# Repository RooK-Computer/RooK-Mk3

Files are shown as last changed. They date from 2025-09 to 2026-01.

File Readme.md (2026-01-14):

# RooK Mk3

RooK is a retro gaming console based on the Raspberry PI CM4. It has all the peripherials you need to be used as an old (modernish) console:

* HDMI for audio and video out.
* Barrel jack for 5V power input, because we love the simplicity of barrel jacks.
* an audio jack for, well... speakers!
* 4 USB ports for up to 4 modern gamepads.
* A cartridge slot!
* 3 Buttons to shut RooK down, exit the game and restart the game.

## How it all works

It's quite simple: instead of having an onboard SD card, the SD cards are installed onto separate PCBs for the cartridges. Once you put a cartridge in, RooK powers up and boots off the SD card in the cartridge.

Of course, unwrapping the SD cards can be tedious, so we built a cartridge reader.

It works out of the box with retropie, except for the three buttons. In this repository you find the software needed to enable those buttons. It's best done immediately after installing retropie, before you customize your setup.

## In this repository

There are 3 folders:

* software contains the sources for the .deb file to easily install overwatch and it's configuration. You'll find the .dep file in there as well, if you don't want to build it yourself. The source is compressed, as we have to ensure ownership and file privileges. Something git tends to ignore ;)
* PCBs contains all the designs for the PCBs involved: 
    * Cartridge - the PCB for cartridges
    * CartridgeReader - should be self-explanatory
    * KeyswitchCarrier - holds the switches for the three keys
    * Mainboard - the biggest of them.
    * Parts and CM4-Files are referenced in the aforementioned design files
* STLs contain the STL files for the case and the cartridge. You'll find our FreeCAD designs in there as well.

## I wanna build one!

Well for now, you have to produce and order the parts yourself. We're working on this. Stay tuned and keep an eye out at [rook.computer](https://rook.computer).

There is a building guide in the wiki.

## License

Unless noted otherwise this work is licensed under Creative Commons Attribution Share Alike 4.0 International.

`SPDX-License-Identifier:  CC-BY-SA-4.0`

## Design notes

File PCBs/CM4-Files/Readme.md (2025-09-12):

# CM4-Files

all files in this folder are files from the Raspberry PI Foundation and are referenced in our designs for footprints.

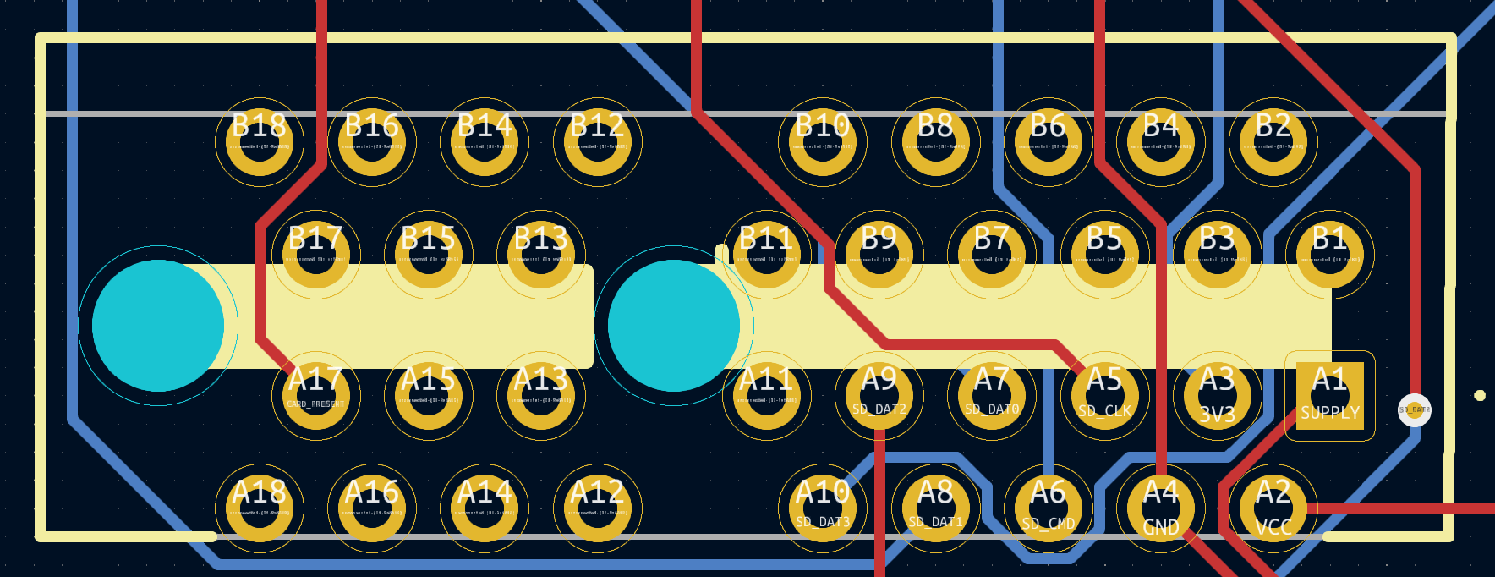
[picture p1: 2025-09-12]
PCBs/CartridgeReader/CartridgeMk3ReaderMk6/Connector.png

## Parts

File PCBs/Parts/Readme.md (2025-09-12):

# Parts

These are the parts used in various PCB designs. We will provide a list of the parts and what they are used for lateron.

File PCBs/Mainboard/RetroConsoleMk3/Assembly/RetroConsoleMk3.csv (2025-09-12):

Id | Designator | Footprint | Quantity | Designation | Supplier and ref
1 | R13,R12,R15,R11,R14,R16 | R_0201_0603Metric | 6 | 33
3 | C3 | C_0201_0603Metric | 1 | 10nF
4 | J7,J5,J6,J3 | USB_A_Molex_67643_Horizontal | 4 | USB_A
5 | J2 | SDCARD_MOLEX_503398-1892 | 1 | Micro_SD_Card
6 | J11 | JST_PH_B2B-PH-K_1x02_P2.00mm_Vertical | 1 | Reset
7 | C7,C5 | C_1206_3216Metric | 2 | 47uF
8 | J10 | SJ335083BTR | 1 | SJ3-35083B-TR
9 | J16,J15 | DF40C100DS04V51 | 2 | DF40C100DS04V51
10 | J8 | PJ114AHSMTTR | 1 | PJ-114AH-SMT-TR
11 | R7,R4 | R_0201_0603Metric | 2 | 220
12 | Y1 | 830108208209 | 1 | 830108208209
13 | R1 | R_0201_0603Metric | 1 | 1k
14 | J13 | JST_PH_B2B-PH-K_1x02_P2.00mm_Vertical | 1 | Quit
16 | R5,R8 | R_0201_0603Metric | 2 | 100
17 | IC2 | SOT65P210X110-6N | 1 | NC7WZ16P6X
18 | R6,R9 | R_0201_0603Metric | 2 | 1.8k
20 | D1 | LED_0201_0603Metric | 1 | GREEN
21 | C6,C4 | C_0201_0603Metric | 2 | 100nF
23 | R10 | R_0201_0603Metric | 1 | 10k
24 | J12 | JST_PH_B2B-PH-K_1x02_P2.00mm_Vertical | 1 | Shutdown
25 | C1,C2 | C_0201_0603Metric | 2 | 14pF
26 | TP5 | TestPoint_Pad_D3.0mm | 1 | GND_SUPPLY
27 | J1 | PinHeader_1x03_P2.54mm_Vertical | 1 | Conn_01x03_Socket
28 | J9 | 18710581 | 1 | 1871058-1
29 | J4 | HDMI_A_Molex_208658-1001_Horizontal | 1 | HDMI_A_1.4
30 | Q1 | IRF2804STRLPBF | 1 | IRLZ34NSTRLPBF
31 | J14 | JST_PH_B4B-PH-K_1x04_P2.00mm_Vertical | 1 | Keys
33 | R2 | R_0201_0603Metric | 1 | 100k
34 | R3 | R_0201_0603Metric | 1 | 12k (+/- 1%)
35 | IC1 | QFN50P600X600X100-37N-D | 1 | USB2514B_M2

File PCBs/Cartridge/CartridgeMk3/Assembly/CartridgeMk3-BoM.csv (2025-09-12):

Id | Designator | Footprint | Quantity | Designation | Supplier and ref
2 | R1,R3,R5,R2,R4 | R_0201_0603Metric | 5 | 10k
3 | J2 | SDCARD_MOLEX_503398-1892 | 1 | Micro_SD_Card

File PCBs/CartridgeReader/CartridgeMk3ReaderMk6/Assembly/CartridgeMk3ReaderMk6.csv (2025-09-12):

Id | Designator | Footprint | Quantity | Designation | Supplier and ref
1 | R3 | R_0201_0603Metric | 1 | 12k +/-1%
2 | R4,R5 | R_0201_0603Metric | 2 | 1k
4 | C4,C3 | C_0201_0603Metric | 2 | 1.0 uF +/- 20%
5 | C6 | C_1206_3216Metric | 1 | 22 uF
6 | R8,R11,R6,R9,R10,R7 | R_0201_0603Metric | 6 | 33
7 | IC1 | QFN50P600X600X90-37N-D | 1 | USB2244I-AEZG-06-TR | https://cn.mouser.com/ProductDetail/Microchip-Technology/USB2244I-AEZG-06-TR
8 | L1 | 74404054470 | 1 | 47 muH | https://cn.mouser.com/ProductDetail/Wurth-Elektronik/74404054470?qs=Zt3UNFD9mQjCehaSX3JlDg%3D%3D
9 | R1,R2 | R_0201_0603Metric | 2 | 5k1
10 | C5 | C_0201_0603Metric | 1 | 1 uF
11 | J1 | 18710581 | 1 | 1871058-1 | https://cn.mouser.com/ProductDetail/TE-Connectivity/1871058-1?qs=%252BoxYCnKeKt%252BrW4wNNMzC1A%3D%3D
12 | Y1 | 830108208209 | 1 | 830108208209 | https://cn.mouser.com/ProductDetail/Wurth-Elektronik/830108208209?qs=hWgE7mdIu5Qfk68EXTEoAw%3D%3D
13 | C2,C1 | C_0201_0603Metric | 2 | 14pF
15 | J2 | USB_C_Receptacle_Molex_105450-0101 | 1 | USB_C_Receptacle
16 | C8 | C_1206_3216Metric | 1 | 4.7 uF
18 | IC2 | ADPL16000AATAT | 1 | ADPL16000AATA+T | https://cn.mouser.com/ProductDetail/Analog-Devices-Maxim-Integrated/ADPL16000AATA%2bT
20 | C7 | C_1206_3216Metric | 1 | 1uF

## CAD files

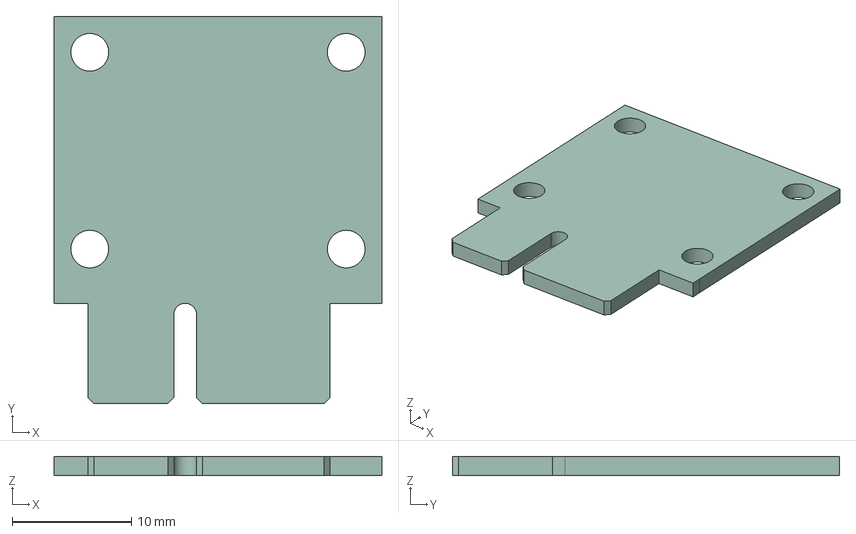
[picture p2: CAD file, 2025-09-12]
PCBs/Cartridge/CartridgeMk3/CartridgeMk1_simple.step
27.5 x 32.5 x 1.60 mm

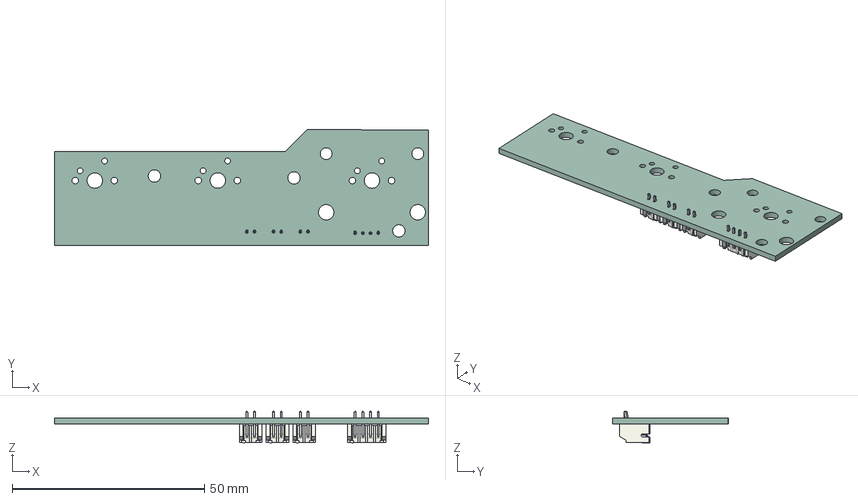
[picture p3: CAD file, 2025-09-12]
PCBs/KeyswitchCarrier/KeyswitchCarrierMk3/KeyswitchCarrierMk3.step
97.2 x 30.0 x 8.25 mm
JST_S4B_PH_K
JST_S2B_PH_K x 3
KeyswitchCarrierMk3_PCB

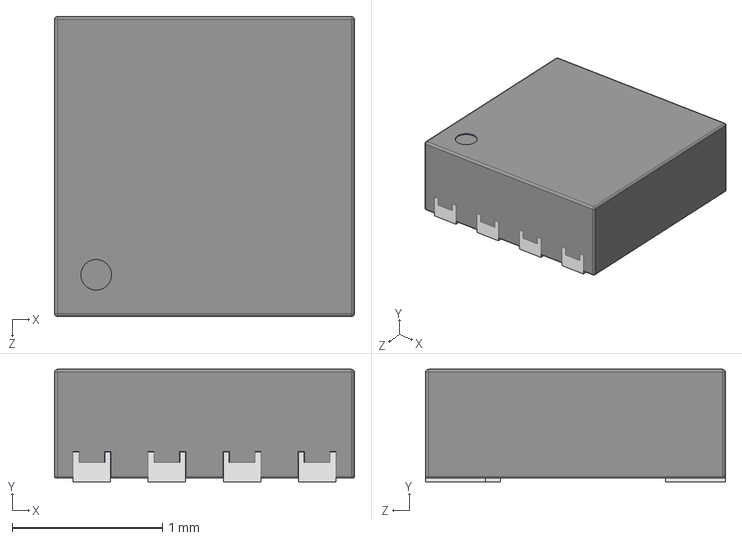
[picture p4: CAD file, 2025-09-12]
PCBs/Parts/LIB_ADPL16000AATA+T/ADPL16000AATA+T/3D/ADPL16000AATA+T.stp
2.00 x 0.75 x 2.00 mm

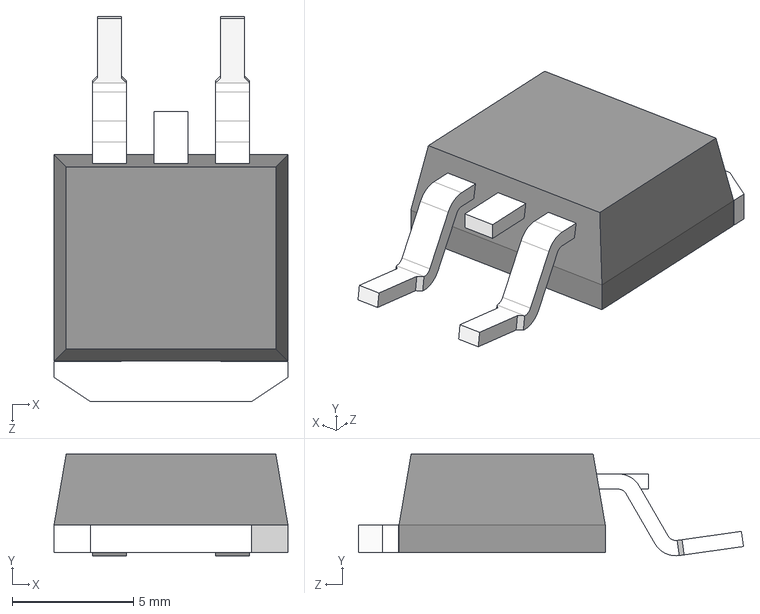
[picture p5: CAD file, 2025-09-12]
PCBs/Parts/LIB_IRLZ34NSTRLPBF/IRLZ34NSTRLPBF/3D/IRLZ34NSTRLPBF.stp
9.65 x 4.19 x 15.9 mm

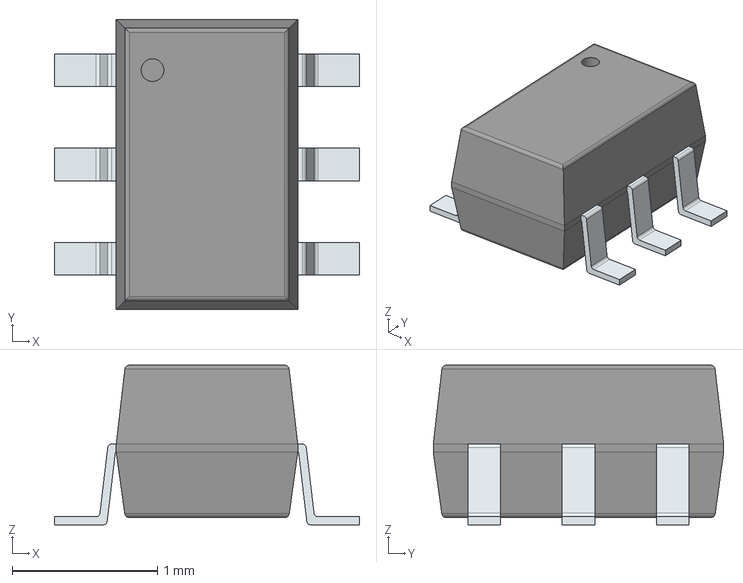
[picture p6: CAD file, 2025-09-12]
PCBs/Parts/LIB_NC7WZ16P6X/NC7WZ16P6X/3D/NC7WZ16P6X.stp
2.10 x 2.00 x 1.10 mm
PinsArrayLR

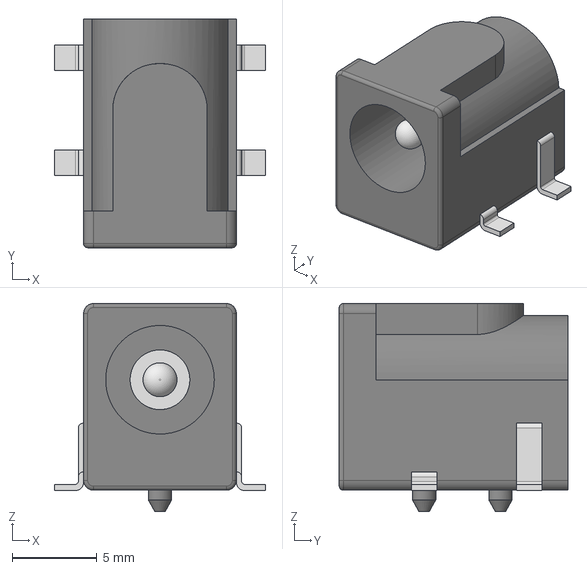
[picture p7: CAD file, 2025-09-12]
PCBs/Parts/LIB_PJ-114AH-SMT-TR/PJ-114AH-SMT-TR/3D/PJ-114AH-SMT-TR.stp
12.4 x 13.5 x 12.3 mm

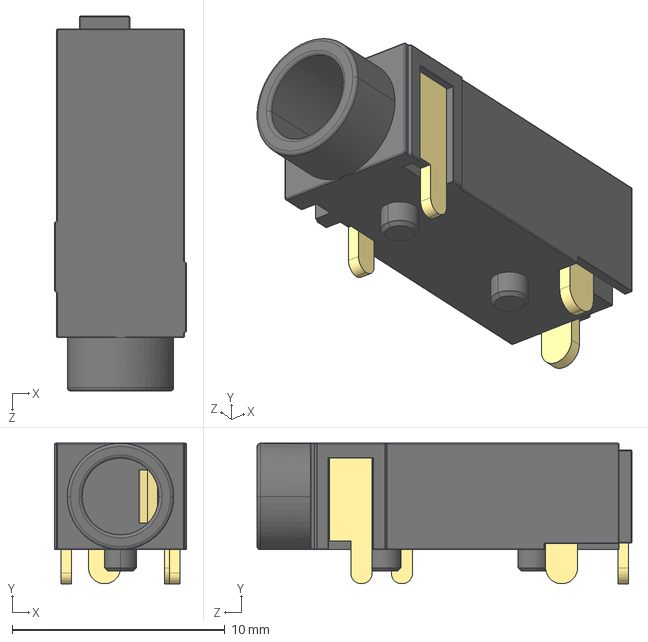
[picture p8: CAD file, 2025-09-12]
PCBs/Parts/LIB_SJ3-35083B-TR/SJ3-35083B-TR/3D/SJ3-35083B-TR.stp
6.20 x 6.60 x 17.6 mm

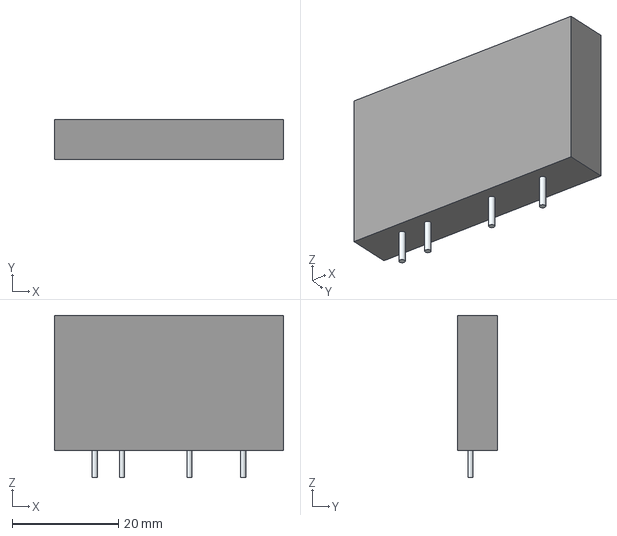
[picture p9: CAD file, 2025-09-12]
PCBs/Parts/LIB_SSRC-240D5/SSRC-240D5/3D/SSRC-240D5.stp
43.1 x 7.60 x 30.5 mm
Leads

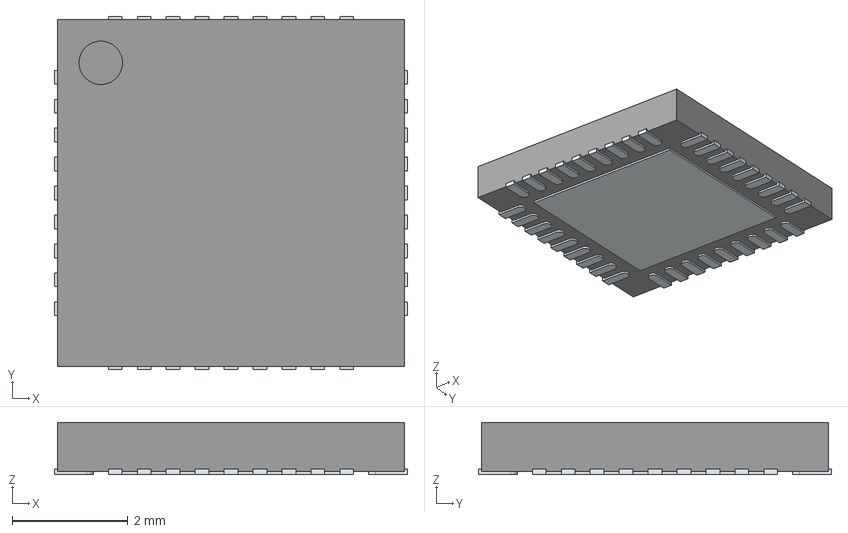
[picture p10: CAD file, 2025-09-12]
PCBs/Parts/LIB_USB2244I-AEZG-06-TR/USB2244I-AEZG-06-TR/3D/USB2244I-AEZG-06-TR.stp
6.10 x 6.10 x 0.9 mm
ThermalPin
PinsArrayLR
PinsArrayTB

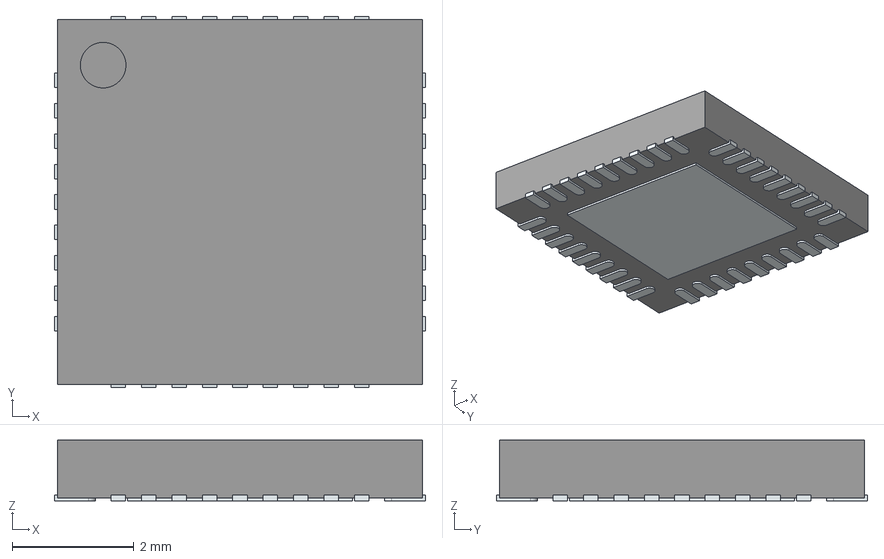
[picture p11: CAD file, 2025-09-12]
PCBs/Parts/LIB_USB2514B_M2/USB2514B_M2/3D/USB2514B_M2.stp
6.10 x 6.10 x 1.00 mm
ThermalPin
PinsArrayLR
PinsArrayTB

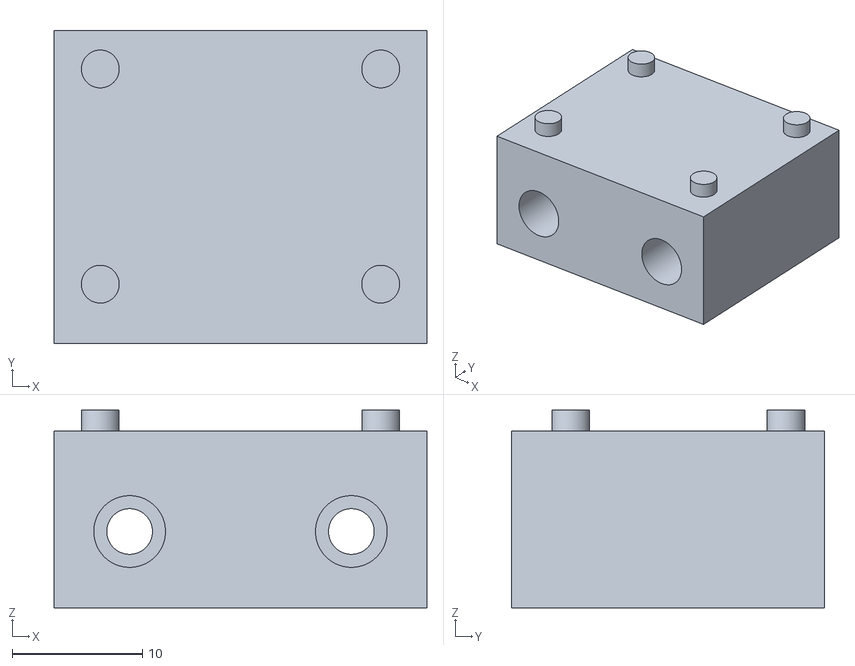
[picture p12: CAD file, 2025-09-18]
STLs/LegoInspiredCase_by_Konnexus_Mk1/CartridgeMk2-STLs/CartridgeMk2-BackSide.stl
28.6 x 24.0 x 15.2

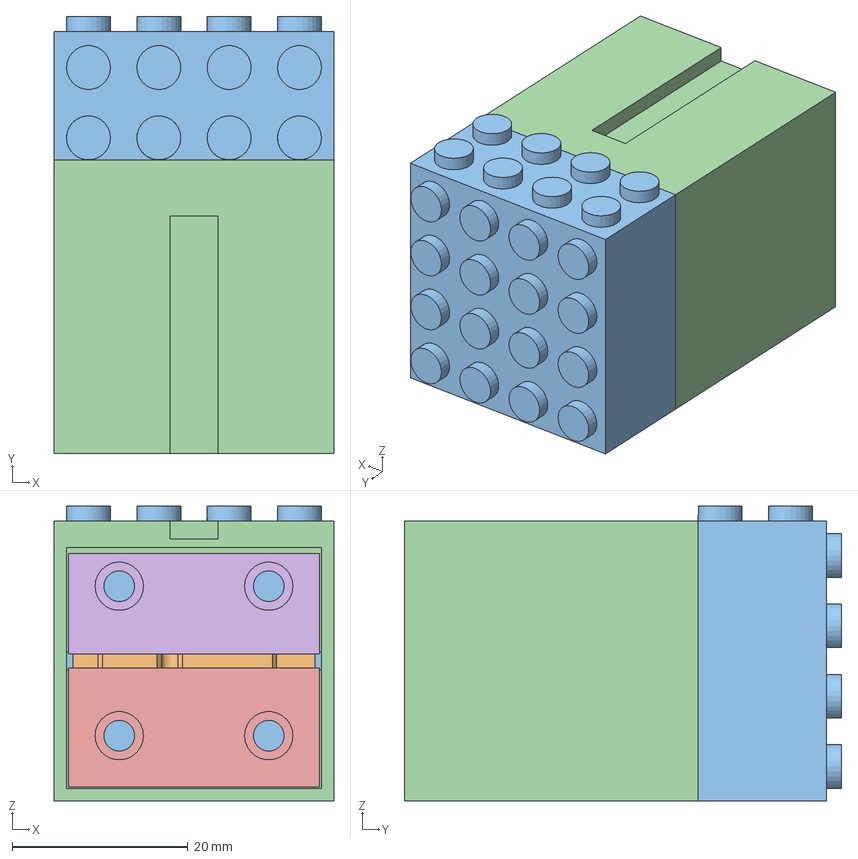
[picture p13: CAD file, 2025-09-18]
STLs/LegoInspiredCase_by_Konnexus_Mk1/CartridgeMk2.FCStd
31.8 x 49.7 x 33.5 mm
CartridgeMk1_PCB
TopPanel
Housing
BackSide
FrontSide

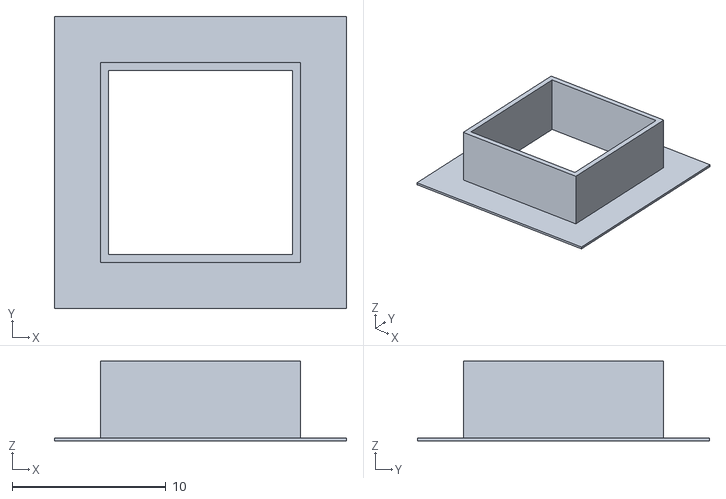
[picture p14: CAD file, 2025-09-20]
STLs/LegoInspiredCase_by_Konnexus_Mk1/Case-STLs/LegoCase_Konnexus_Mk1-Shutdown Button Border.stl
19.0 x 19.0 x 5.20

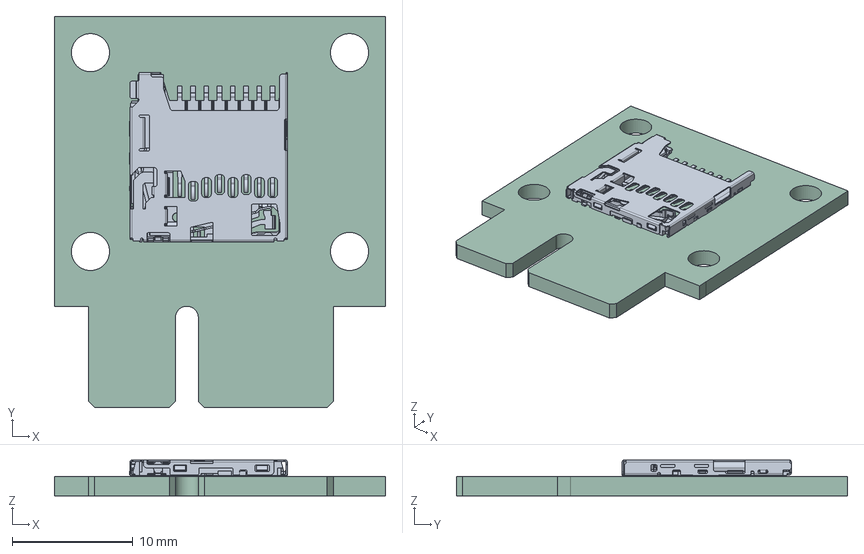
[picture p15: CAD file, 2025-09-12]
PCBs/Cartridge/CartridgeMk3/CartridgeMk3.step
27.5 x 32.5 x 2.98 mm
CartridgeMk1_PCB

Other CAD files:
STLs/LegoInspiredCase_by_Konnexus_Mk1/CartridgeMk2-STLs/CartridgeMk2-TopPanel.stl
STLs/LegoInspiredCase_by_Konnexus_Mk1/Case-STLs/LegoCase_Konnexus_Mk1-Reset Button fat Border.stl
STLs/LegoInspiredCase_by_Konnexus_Mk1/CartridgeMk2-STLs/CartridgeMk2-FrontSide.stl
STLs/LegoInspiredCase_by_Konnexus_Mk1/Case-STLs/LegoCase_Konnexus_Mk1-Quit Button fat Border.stl
PCBs/Parts/105450-0101/3D/105450-0101.stp
PCBs/Parts/LIB_1871058-1/1871058-1/3D/1871058-1.stp
PCBs/Parts/LIB_1871058-1/1871058-1/Allegro/18710581.psm
PCBs/Parts/LIB_1871058-1/1871058-1/DEHDL/1871058_1/chips/chips.prt
PCBs/Parts/LIB_74404054470/74404054470/3D/74404054470.stp
PCBs/Parts/LIB_74404054470/74404054470/Allegro/74404054470.psm
PCBs/Parts/LIB_74404054470/74404054470/DEHDL/74404054470/chips/chips.prt
PCBs/Parts/LIB_830108208209/830108208209/3D/830108208209.stp
PCBs/Parts/LIB_830108208209/830108208209/Allegro/830108208209.psm
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

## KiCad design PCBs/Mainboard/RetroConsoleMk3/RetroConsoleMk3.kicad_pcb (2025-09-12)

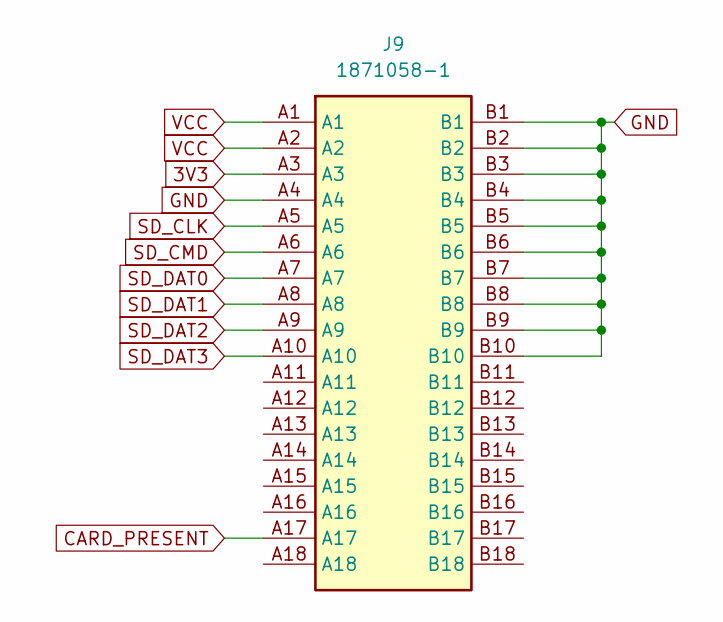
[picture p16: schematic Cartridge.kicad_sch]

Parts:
J9: 1871058-1; 18710581; Manufacturer_Part_Number 1871058-1; Mouser Part Number 571-1871058-1

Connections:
3V3: J9.A3; also elsewhere on the board
CARD_PRESENT: J9.A17; also elsewhere on the board
GND: J9.A4, J9.B1, J9.B2, J9.B3, J9.B4, J9.B5, J9.B6, J9.B7, J9.B8, J9.B9, J9.B10; also elsewhere on the board
SD_CLK: J9.A5; also elsewhere on the board
SD_CMD: J9.A6; also elsewhere on the board
SD_DAT0: J9.A7; also elsewhere on the board
SD_DAT1: J9.A8; also elsewhere on the board
SD_DAT2: J9.A9; also elsewhere on the board
SD_DAT3: J9.A10; also elsewhere on the board
VCC: J9.A1, J9.A2; also elsewhere on the board

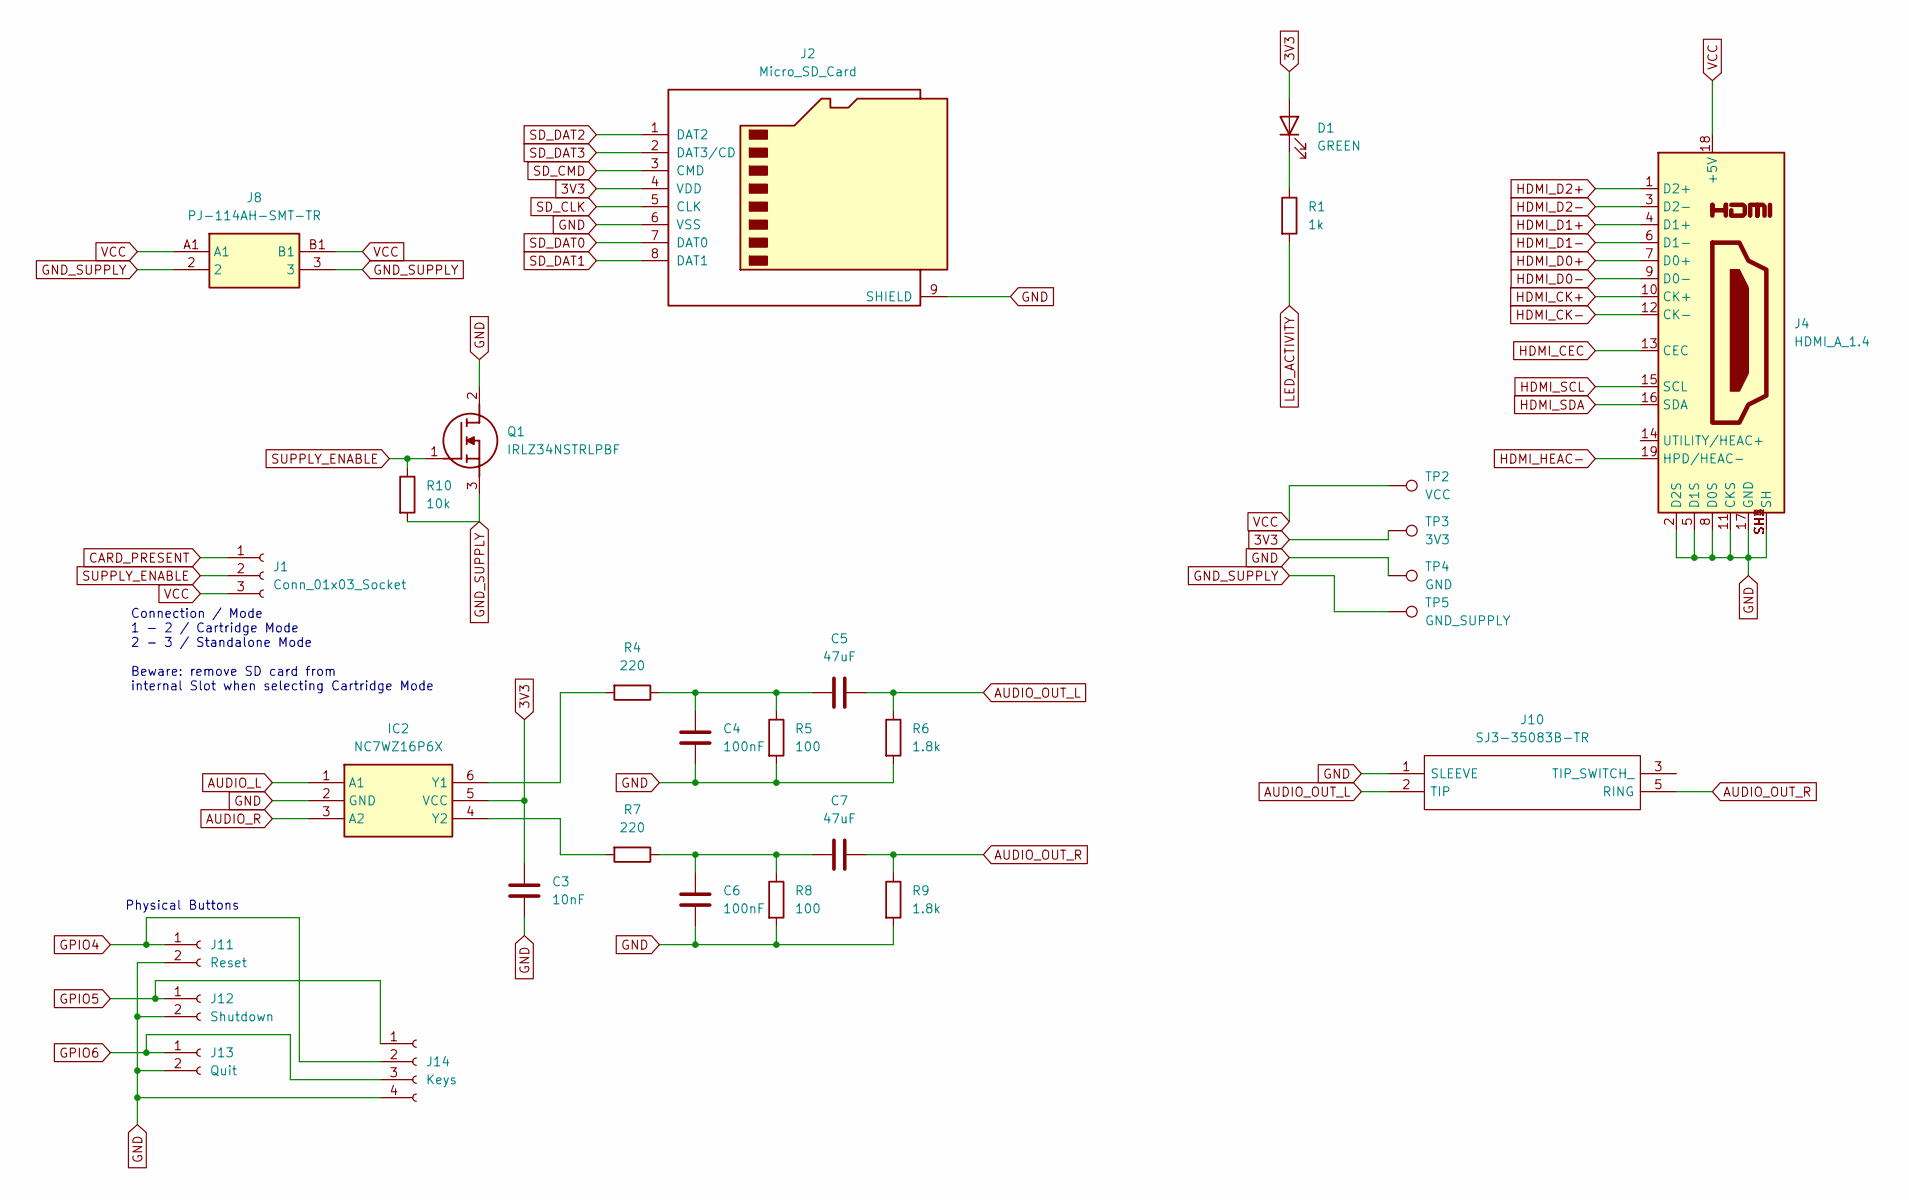
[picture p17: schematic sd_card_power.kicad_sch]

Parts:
C3: 10nF; C_0201_0603Metric
C4, C6: 100nF; C_0201_0603Metric
C5, C7: 47uF; C_1206_3216Metric
D1: GREEN; LED_0201_0603Metric
IC2: NC7WZ16P6X; SOT65P210X110-6N; Manufacturer_Part_Number NC7WZ16P6X; Mouser Part Number 512-NC7WZ16P6X
J1: Conn_01x03_Socket; PinHeader_1x03_P2.54mm_Vertical
J2: Micro_SD_Card; SDCARD_MOLEX_503398-1892
J4: HDMI_A_1.4; HDMI_A_Molex_208658-1001_Horizontal
J8: PJ-114AH-SMT-TR; PJ114AHSMTTR; Manufacturer_Part_Number PJ-114AH-SMT-TR; Mouser Part Number 179-PJ-114AH-SMT-TR
J10: SJ3-35083B-TR; SJ335083BTR; Manufacturer_Part_Number SJ3-35083B-TR; Mouser Part Number 179-SJ3-35083B-TR
J11: Reset; JST_PH_B2B-PH-K_1x02_P2.00mm_Vertical
J12: Shutdown; JST_PH_B2B-PH-K_1x02_P2.00mm_Vertical
J13: Quit; JST_PH_B2B-PH-K_1x02_P2.00mm_Vertical
J14: Keys; JST_PH_B4B-PH-K_1x04_P2.00mm_Vertical
Q1: IRLZ34NSTRLPBF; IRF2804STRLPBF; Manufacturer_Part_Number IRLZ34NSTRLPBF; Mouser Part Number 942-IRLZ34NSTRLPBF
R1: 1k; R_0201_0603Metric
R4, R7: 220; R_0201_0603Metric
R5, R8: 100; R_0201_0603Metric
R6, R9: 1.8k; R_0201_0603Metric
R10: 10k; R_0201_0603Metric
TP2: VCC; TestPoint_Pad_D3.0mm
TP3: 3V3; TestPoint_Pad_D3.0mm
TP4: GND; TestPoint_Pad_D3.0mm
TP5: GND_SUPPLY; TestPoint_Pad_D3.0mm

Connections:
3V3: C3.1, D1.2 (A), IC2.5 (VCC), J2.4 (VDD), TP3.1; also elsewhere on the board
AUDIO_L: IC2.1 (A1); also elsewhere on the board
AUDIO_OUT_L: C5.1, J10.2 (TIP), R6.1
AUDIO_OUT_R: C7.1, J10.5 (RING), R9.1
AUDIO_R: IC2.3 (A2); also elsewhere on the board
CARD_PRESENT: J1.1; also elsewhere on the board
GND: C3.2, C4.2, C6.2, IC2.2 (GND), J2.6 (VSS), J2.9 (SHIELD), J4.2 (D2S), J4.5 (D1S), J4.8 (D0S), J4.11 (CKS), J4.17 (GND), J4.SH1 (SH), J4.SH2 (SH), J4.SH3 (SH), J4.SH4 (SH), J10.1 (SLEEVE), J11.2, J12.2, J13.2, J14.4, Q1.2 (D), R5.2, R6.2, R8.2, R9.2, TP4.1; also elsewhere on the board
GND_SUPPLY: J8.2, J8.3, Q1.3 (S), R10.2, TP5.1
GPIO4: J11.1, J14.2; also elsewhere on the board
GPIO5: J12.1, J14.1; also elsewhere on the board
GPIO6: J13.1, J14.3; also elsewhere on the board
HDMI_CEC: J4.13 (CEC); also elsewhere on the board
HDMI_CK+: J4.10 (CK+); also elsewhere on the board
HDMI_CK-: J4.12 (CK-); also elsewhere on the board
HDMI_D0+: J4.7 (D0+); also elsewhere on the board
HDMI_D0-: J4.9 (D0-); also elsewhere on the board
HDMI_D1+: J4.4 (D1+); also elsewhere on the board
HDMI_D1-: J4.6 (D1-); also elsewhere on the board
HDMI_D2+: J4.1 (D2+); also elsewhere on the board
HDMI_D2-: J4.3 (D2-); also elsewhere on the board
HDMI_HEAC-: J4.19 (HPD/HEAC-); also elsewhere on the board
HDMI_SCL: J4.15 (SCL); also elsewhere on the board
HDMI_SDA: J4.16 (SDA); also elsewhere on the board
LED_ACTIVITY: R1.2; also elsewhere on the board
unnamed: C4.1, C5.2, R4.1, R5.1
unnamed: C6.1, C7.2, R7.1, R8.1
unnamed: D1.1 (K), R1.1
unnamed: IC2.6 (Y1), R4.2
unnamed: IC2.4 (Y2), R7.2
SD_CLK: J2.5 (CLK); also elsewhere on the board
SD_CMD: J2.3 (CMD); also elsewhere on the board
SD_DAT0: J2.7 (DAT0); also elsewhere on the board
SD_DAT1: J2.8 (DAT1); also elsewhere on the board
SD_DAT2: J2.1 (DAT2); also elsewhere on the board
SD_DAT3: J2.2 (DAT3/CD); also elsewhere on the board
SUPPLY_ENABLE: J1.2, Q1.1 (G), R10.1
VCC: J1.3, J4.18 (+5V), J8.A1, J8.B1, TP2.1; also elsewhere on the board

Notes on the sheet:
Physical Buttons
Connection / Mode 1 - 2 / Cartridge Mode 2 - 3 / Standalone Mode Beware: remove SD card from internal Slot when selecting Cartridge Mode

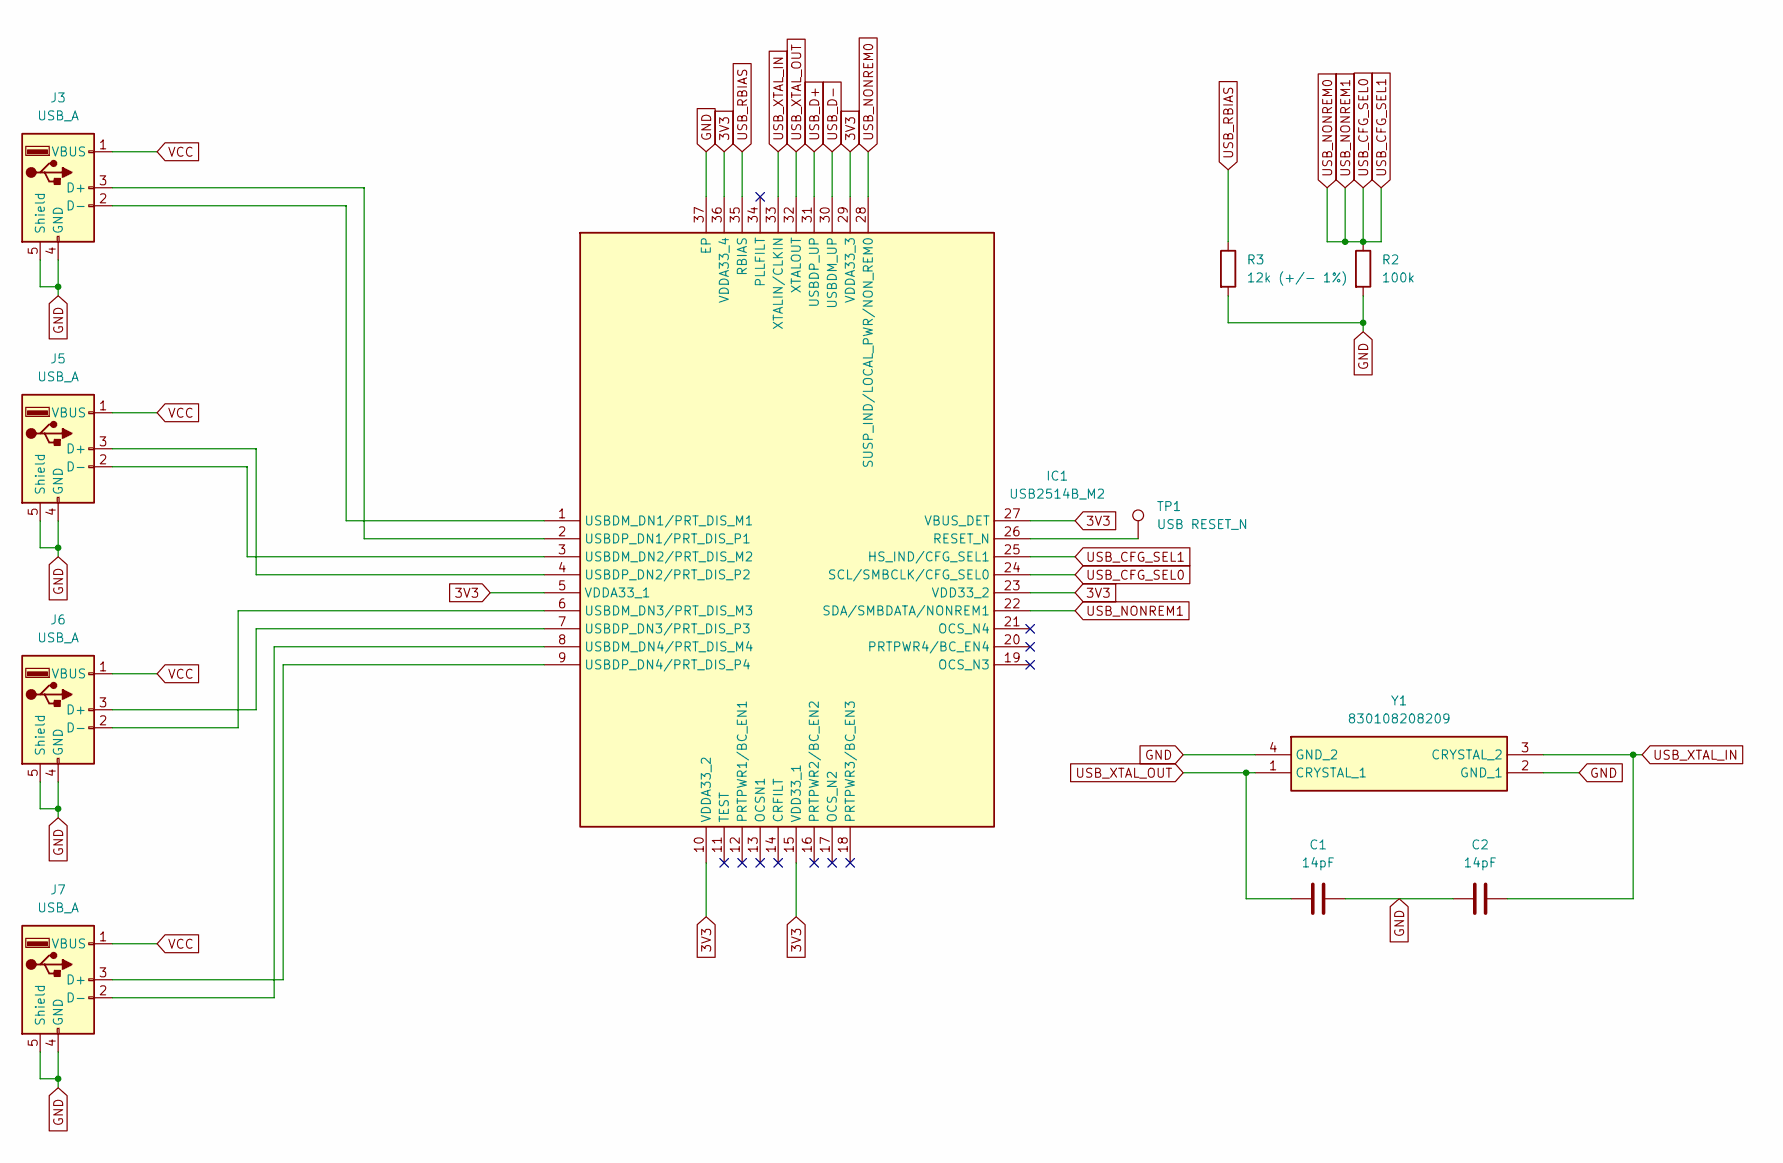
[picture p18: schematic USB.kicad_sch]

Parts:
C1, C2: 14pF; C_0201_0603Metric
IC1: USB2514B_M2; QFN50P600X600X100-37N-D; Manufacturer_Part_Number USB2514B/M2; Mouser Part Number 579-USB2514B/M2
J3, J5, J6, J7: USB_A; USB_A_Molex_67643_Horizontal
R2: 100k; R_0201_0603Metric
R3: 12k (+/- 1%); R_0201_0603Metric
TP1: USB RESET_N; TestPoint_Pad_D3.0mm
Y1: 830108208209; Manufacturer_Part_Number 830108208209; Mouser Part Number 710-830108208209

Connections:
3V3: IC1.5 (VDDA33_1), IC1.10 (VDDA33_2), IC1.15 (VDD33_1), IC1.23 (VDD33_2), IC1.27 (VBUS_DET), IC1.29 (VDDA33_3), IC1.36 (VDDA33_4); also elsewhere on the board
GND: C1.1, C2.2, IC1.37 (EP), J3.4 (GND), J3.5 (Shield), J5.4 (GND), J5.5 (Shield), J6.4 (GND), J6.5 (Shield), J7.4 (GND), J7.5 (Shield), R2.2, R3.2, Y1.2 (GND_1), Y1.4 (GND_2); also elsewhere on the board
unnamed: IC1.26 (RESET_N), TP1.1
unnamed: IC1.1 (USBDM_DN1/PRT_DIS_M1), J3.2 (D-)
unnamed: IC1.3 (USBDM_DN2/PRT_DIS_M2), J5.2 (D-)
unnamed: IC1.6 (USBDM_DN3/PRT_DIS_M3), J6.2 (D-)
unnamed: IC1.8 (USBDM_DN4/PRT_DIS_M4), J7.2 (D-)
unnamed: IC1.2 (USBDP_DN1/PRT_DIS_P1), J3.3 (D+)
unnamed: IC1.4 (USBDP_DN2/PRT_DIS_P2), J5.3 (D+)
unnamed: IC1.7 (USBDP_DN3/PRT_DIS_P3), J6.3 (D+)
unnamed: IC1.9 (USBDP_DN4/PRT_DIS_P4), J7.3 (D+)
USB_CFG_SEL0: IC1.22 (SDA/SMBDATA/NONREM1), IC1.24 (SCL/SMBCLK/CFG_SEL0), IC1.25 (HS_IND/CFG_SEL1), IC1.28 (SUSP_IND/LOCAL_PWR/NON_REM0), R2.1
USB_D+: IC1.31 (USBDP_UP); also elsewhere on the board
USB_D-: IC1.30 (USBDM_UP); also elsewhere on the board
USB_RBIAS: IC1.35 (RBIAS), R3.1
USB_XTAL_IN: C2.1, IC1.33 (XTALIN/CLKIN), Y1.3 (CRYSTAL_2)
USB_XTAL_OUT: C1.2, IC1.32 (XTALOUT), Y1.1 (CRYSTAL_1)
VCC: J3.1 (VBUS), J5.1 (VBUS), J6.1 (VBUS), J7.1 (VBUS); also elsewhere on the board

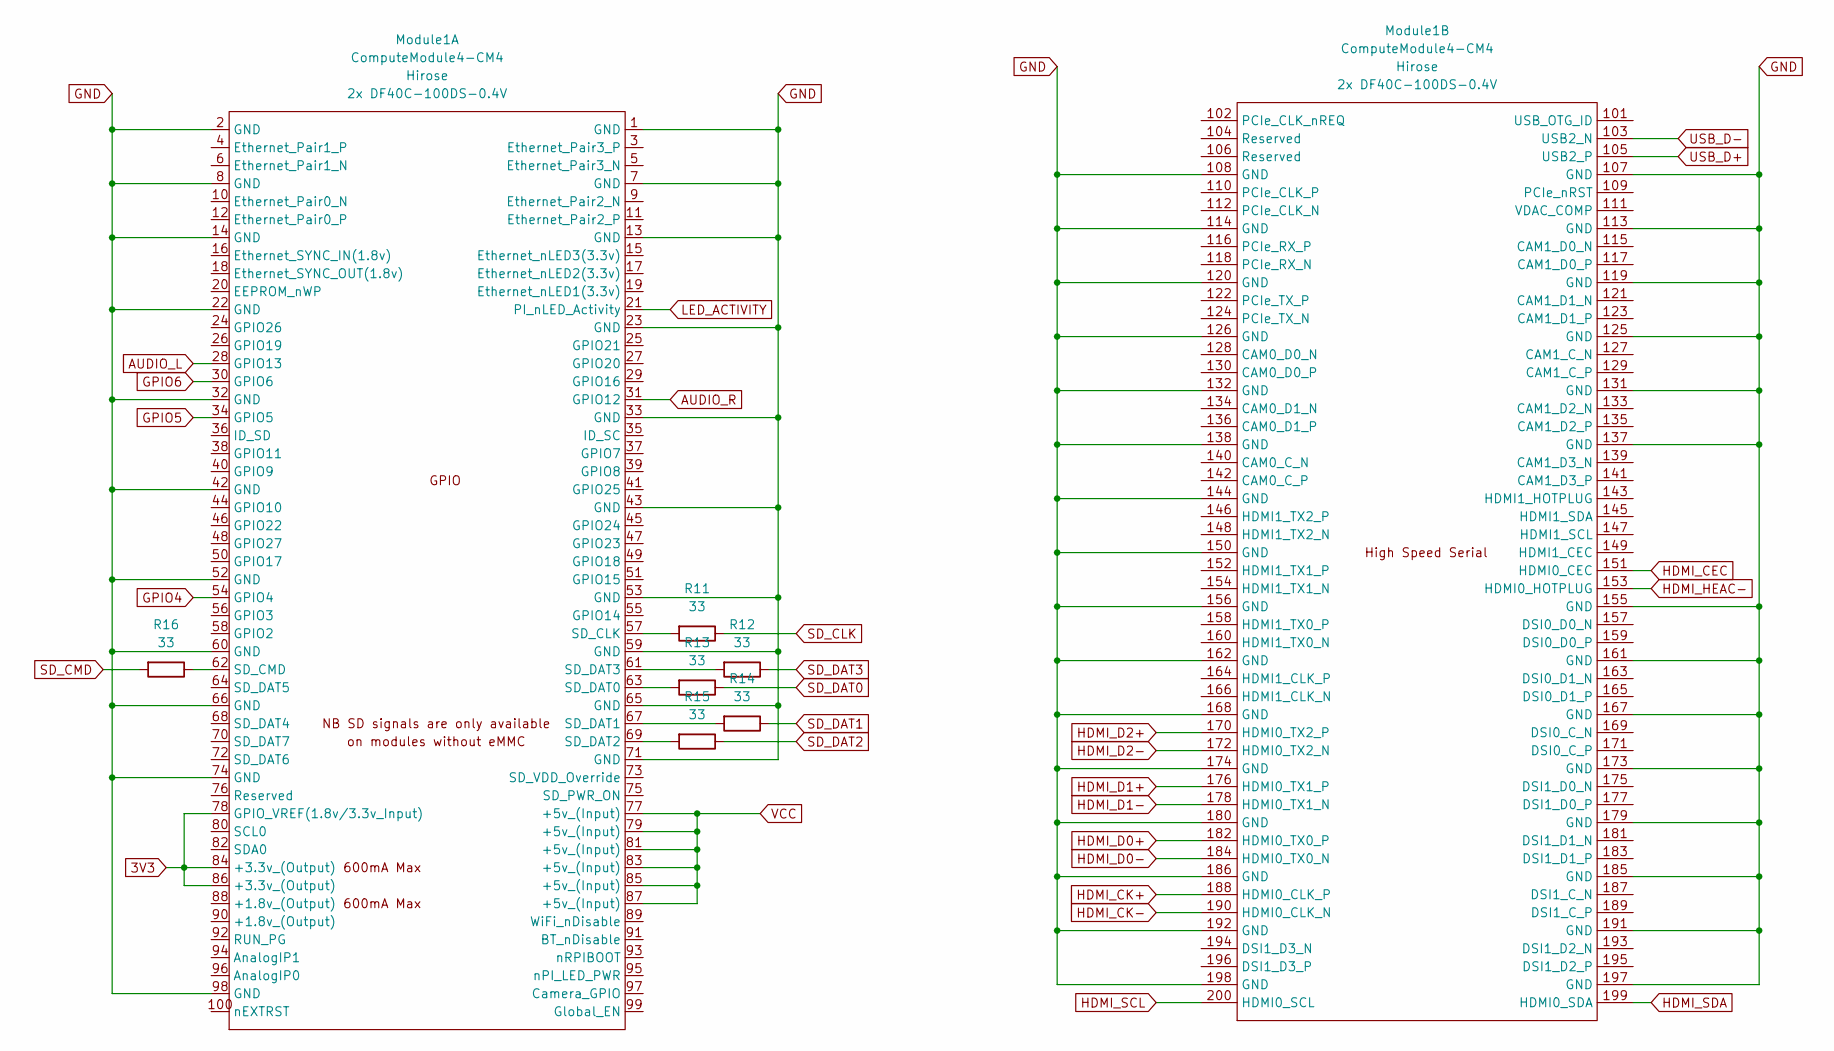
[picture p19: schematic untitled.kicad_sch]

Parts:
Module1: ComputeModule4-CM4; Raspberry-Pi-4-Compute-Module
R11, R12, R13, R14, R15, R16: 33; R_0201_0603Metric

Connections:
3V3: Module1.78 (GPIO_VREF(1.8v/3.3v_Input)), Module1.84 (+3.3v_(Output)), Module1.86 (+3.3v_(Output)); also elsewhere on the board
AUDIO_L: Module1.28 (GPIO13); also elsewhere on the board
AUDIO_R: Module1.31 (GPIO12); also elsewhere on the board
GND: Module1.1 (GND), Module1.2 (GND), Module1.7 (GND), Module1.8 (GND), Module1.13 (GND), Module1.14 (GND), Module1.22 (GND), Module1.23 (GND), Module1.32 (GND), Module1.33 (GND), Module1.42 (GND), Module1.43 (GND), Module1.52 (GND), Module1.53 (GND), Module1.59 (GND), Module1.60 (GND), Module1.65 (GND), Module1.66 (GND), Module1.71 (GND), Module1.74 (GND), Module1.98 (GND), Module1.107 (GND), Module1.108 (GND), Module1.113 (GND), Module1.114 (GND), Module1.119 (GND), Module1.120 (GND), Module1.125 (GND), Module1.126 (GND), Module1.131 (GND), Module1.132 (GND), Module1.137 (GND), Module1.138 (GND), Module1.144 (GND), Module1.150 (GND), Module1.155 (GND), Module1.156 (GND), Module1.161 (GND), Module1.162 (GND), Module1.167 (GND), Module1.168 (GND), Module1.173 (GND), Module1.174 (GND), Module1.179 (GND), Module1.180 (GND), Module1.185 (GND), Module1.186 (GND), Module1.191 (GND), Module1.192 (GND), Module1.197 (GND), Module1.198 (GND); also elsewhere on the board
GPIO4: Module1.54 (GPIO4); also elsewhere on the board
GPIO5: Module1.34 (GPIO5); also elsewhere on the board
GPIO6: Module1.30 (GPIO6); also elsewhere on the board
HDMI_CEC: Module1.151 (HDMI0_CEC); also elsewhere on the board
HDMI_CK+: Module1.188 (HDMI0_CLK_P); also elsewhere on the board
HDMI_CK-: Module1.190 (HDMI0_CLK_N); also elsewhere on the board
HDMI_D0+: Module1.182 (HDMI0_TX0_P); also elsewhere on the board
HDMI_D0-: Module1.184 (HDMI0_TX0_N); also elsewhere on the board
HDMI_D1+: Module1.176 (HDMI0_TX1_P); also elsewhere on the board
HDMI_D1-: Module1.178 (HDMI0_TX1_N); also elsewhere on the board
HDMI_D2+: Module1.170 (HDMI0_TX2_P); also elsewhere on the board
HDMI_D2-: Module1.172 (HDMI0_TX2_N); also elsewhere on the board
HDMI_HEAC-: Module1.153 (HDMI0_HOTPLUG); also elsewhere on the board
HDMI_SCL: Module1.200 (HDMI0_SCL); also elsewhere on the board
HDMI_SDA: Module1.199 (HDMI0_SDA); also elsewhere on the board
LED_ACTIVITY: Module1.21 (PI_nLED_Activity); also elsewhere on the board
unnamed: Module1.57 (SD_CLK), R11.2
unnamed: Module1.62 (SD_CMD), R16.1
unnamed: Module1.63 (SD_DAT0), R13.2
unnamed: Module1.67 (SD_DAT1), R14.2
unnamed: Module1.69 (SD_DAT2), R15.2
unnamed: Module1.61 (SD_DAT3), R12.2
SD_CLK: R11.1; also elsewhere on the board
SD_CMD: R16.2; also elsewhere on the board
SD_DAT0: R13.1; also elsewhere on the board
SD_DAT1: R14.1; also elsewhere on the board
SD_DAT2: R15.1; also elsewhere on the board
SD_DAT3: R12.1; also elsewhere on the board
USB_D+: Module1.105 (USB2_P); also elsewhere on the board
USB_D-: Module1.103 (USB2_N); also elsewhere on the board
VCC: Module1.77 (+5v_(Input)), Module1.79 (+5v_(Input)), Module1.81 (+5v_(Input)), Module1.83 (+5v_(Input)), Module1.85 (+5v_(Input)), Module1.87 (+5v_(Input)); also elsewhere on the board

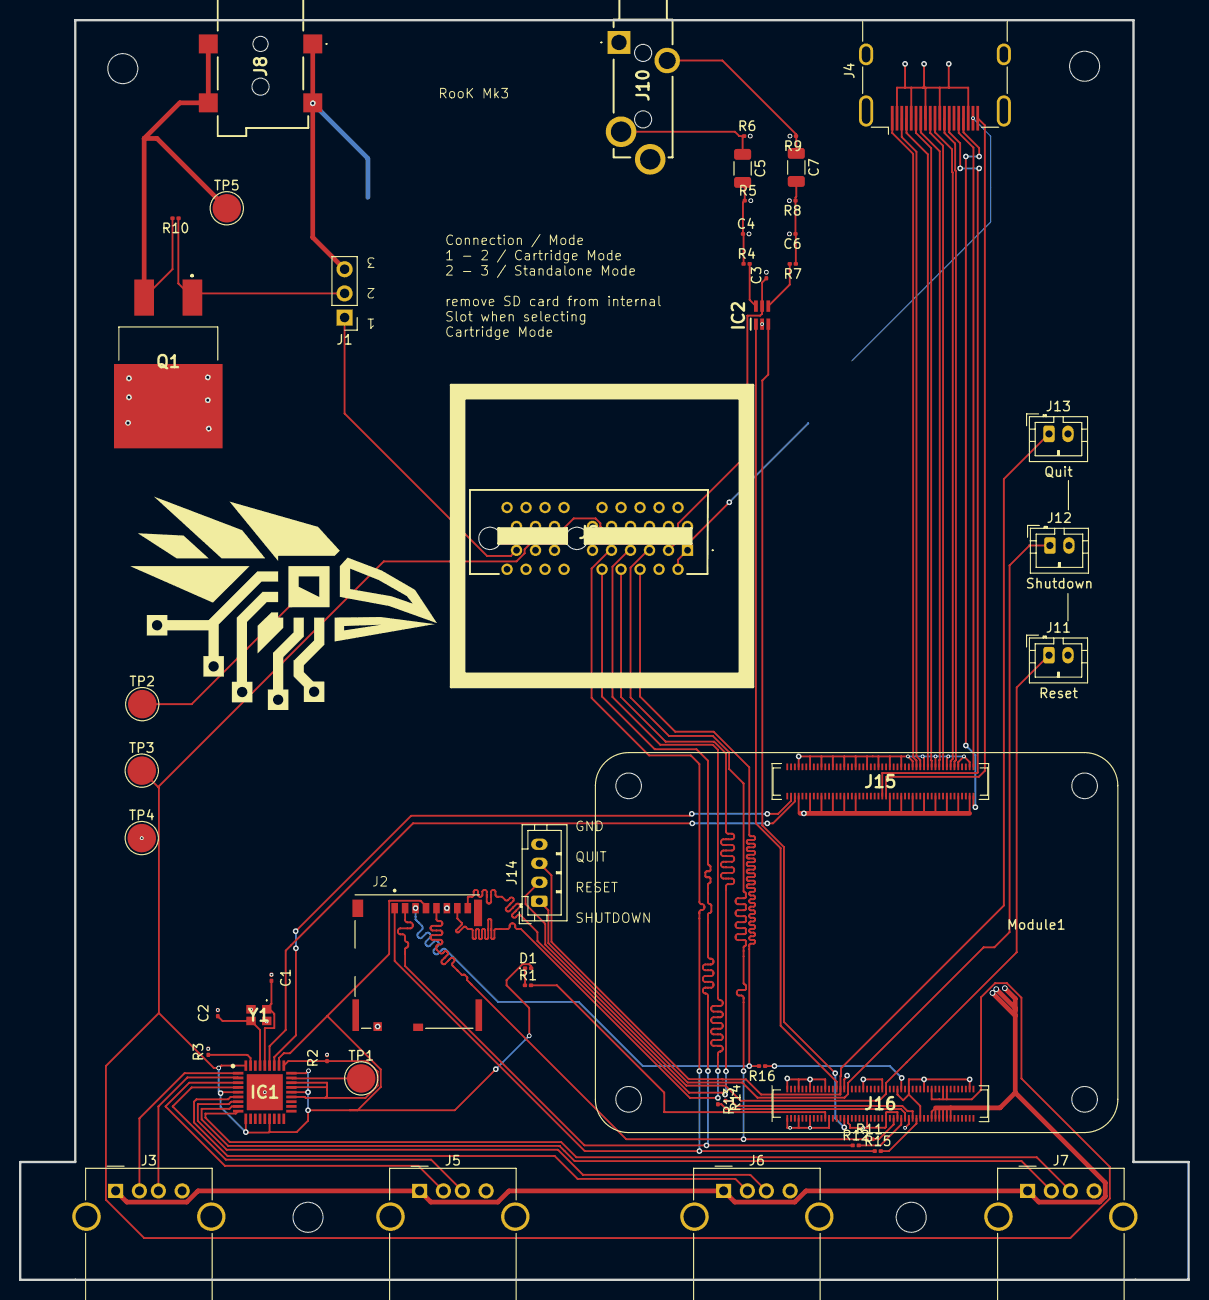
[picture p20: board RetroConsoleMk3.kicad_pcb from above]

Board: 2 copper layers, 123.0 x 132.6 mm, 50 parts (0 on the bottom side), 58 nets.

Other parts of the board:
J15, J16: DF40C100DS04V51

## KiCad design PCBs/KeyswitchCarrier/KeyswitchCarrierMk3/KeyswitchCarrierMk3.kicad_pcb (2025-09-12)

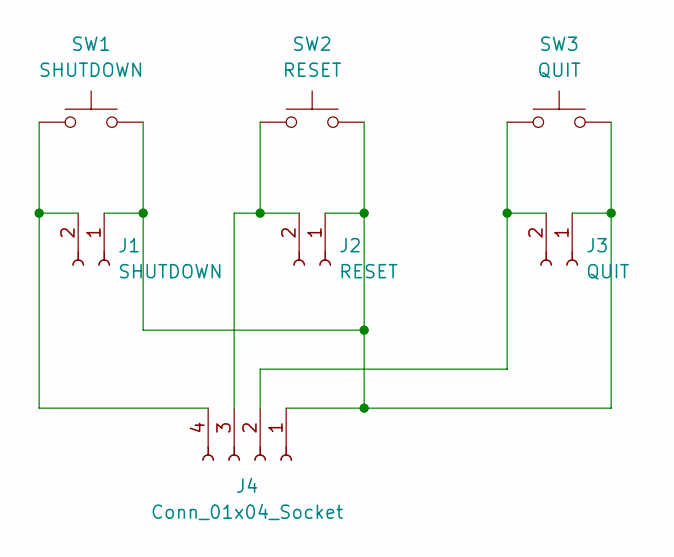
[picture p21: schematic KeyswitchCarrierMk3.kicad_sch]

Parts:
J1: SHUTDOWN; JST_PH_S2B-PH-K_1x02_P2.00mm_Horizontal
J2: RESET; JST_PH_S2B-PH-K_1x02_P2.00mm_Horizontal
J3: QUIT; JST_PH_S2B-PH-K_1x02_P2.00mm_Horizontal
J4: Conn_01x04_Socket; JST_PH_S4B-PH-K_1x04_P2.00mm_Horizontal
SW1: SHUTDOWN; SW_Cherry_MX_1.00u_PCB
SW2: RESET; SW_Cherry_MX_1.00u_PCB
SW3: QUIT; SW_Cherry_MX_1.00u_PCB

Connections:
unnamed: J1.1, J2.1, J3.1, J4.1, SW1.2, SW2.2, SW3.2
unnamed: J1.2, J4.4, SW1.1
unnamed: J2.2, J4.3, SW2.1
unnamed: J3.2, J4.2, SW3.1

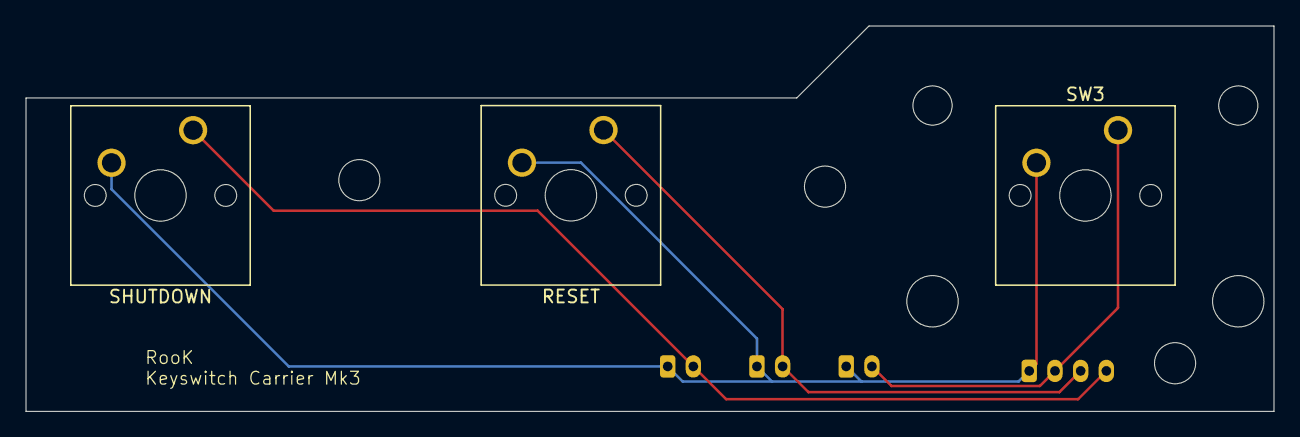
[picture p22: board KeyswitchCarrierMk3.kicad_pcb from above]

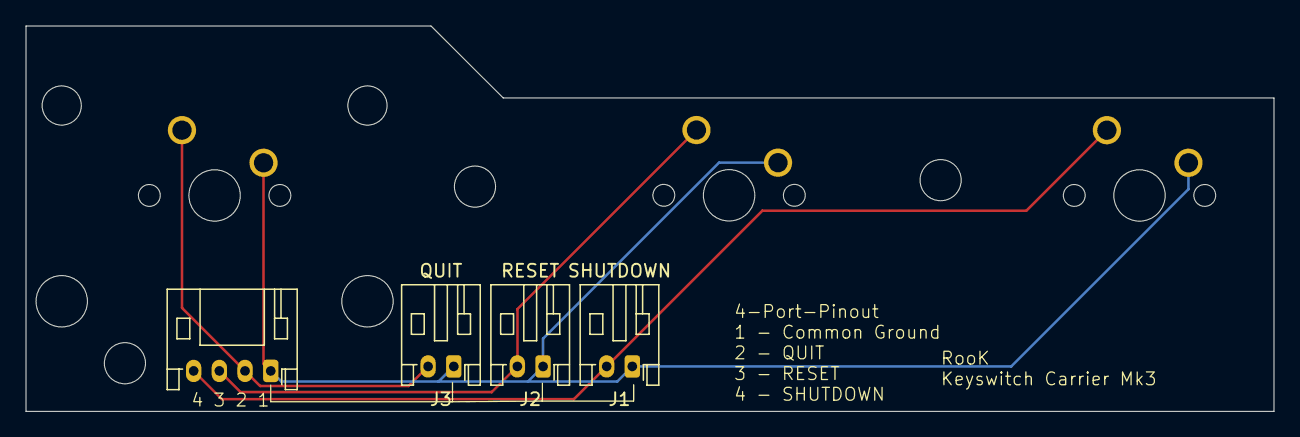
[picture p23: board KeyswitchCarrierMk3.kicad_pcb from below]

Board: 2 copper layers, 97.1 x 30.0 mm, 7 parts (4 on the bottom side), 4 nets.

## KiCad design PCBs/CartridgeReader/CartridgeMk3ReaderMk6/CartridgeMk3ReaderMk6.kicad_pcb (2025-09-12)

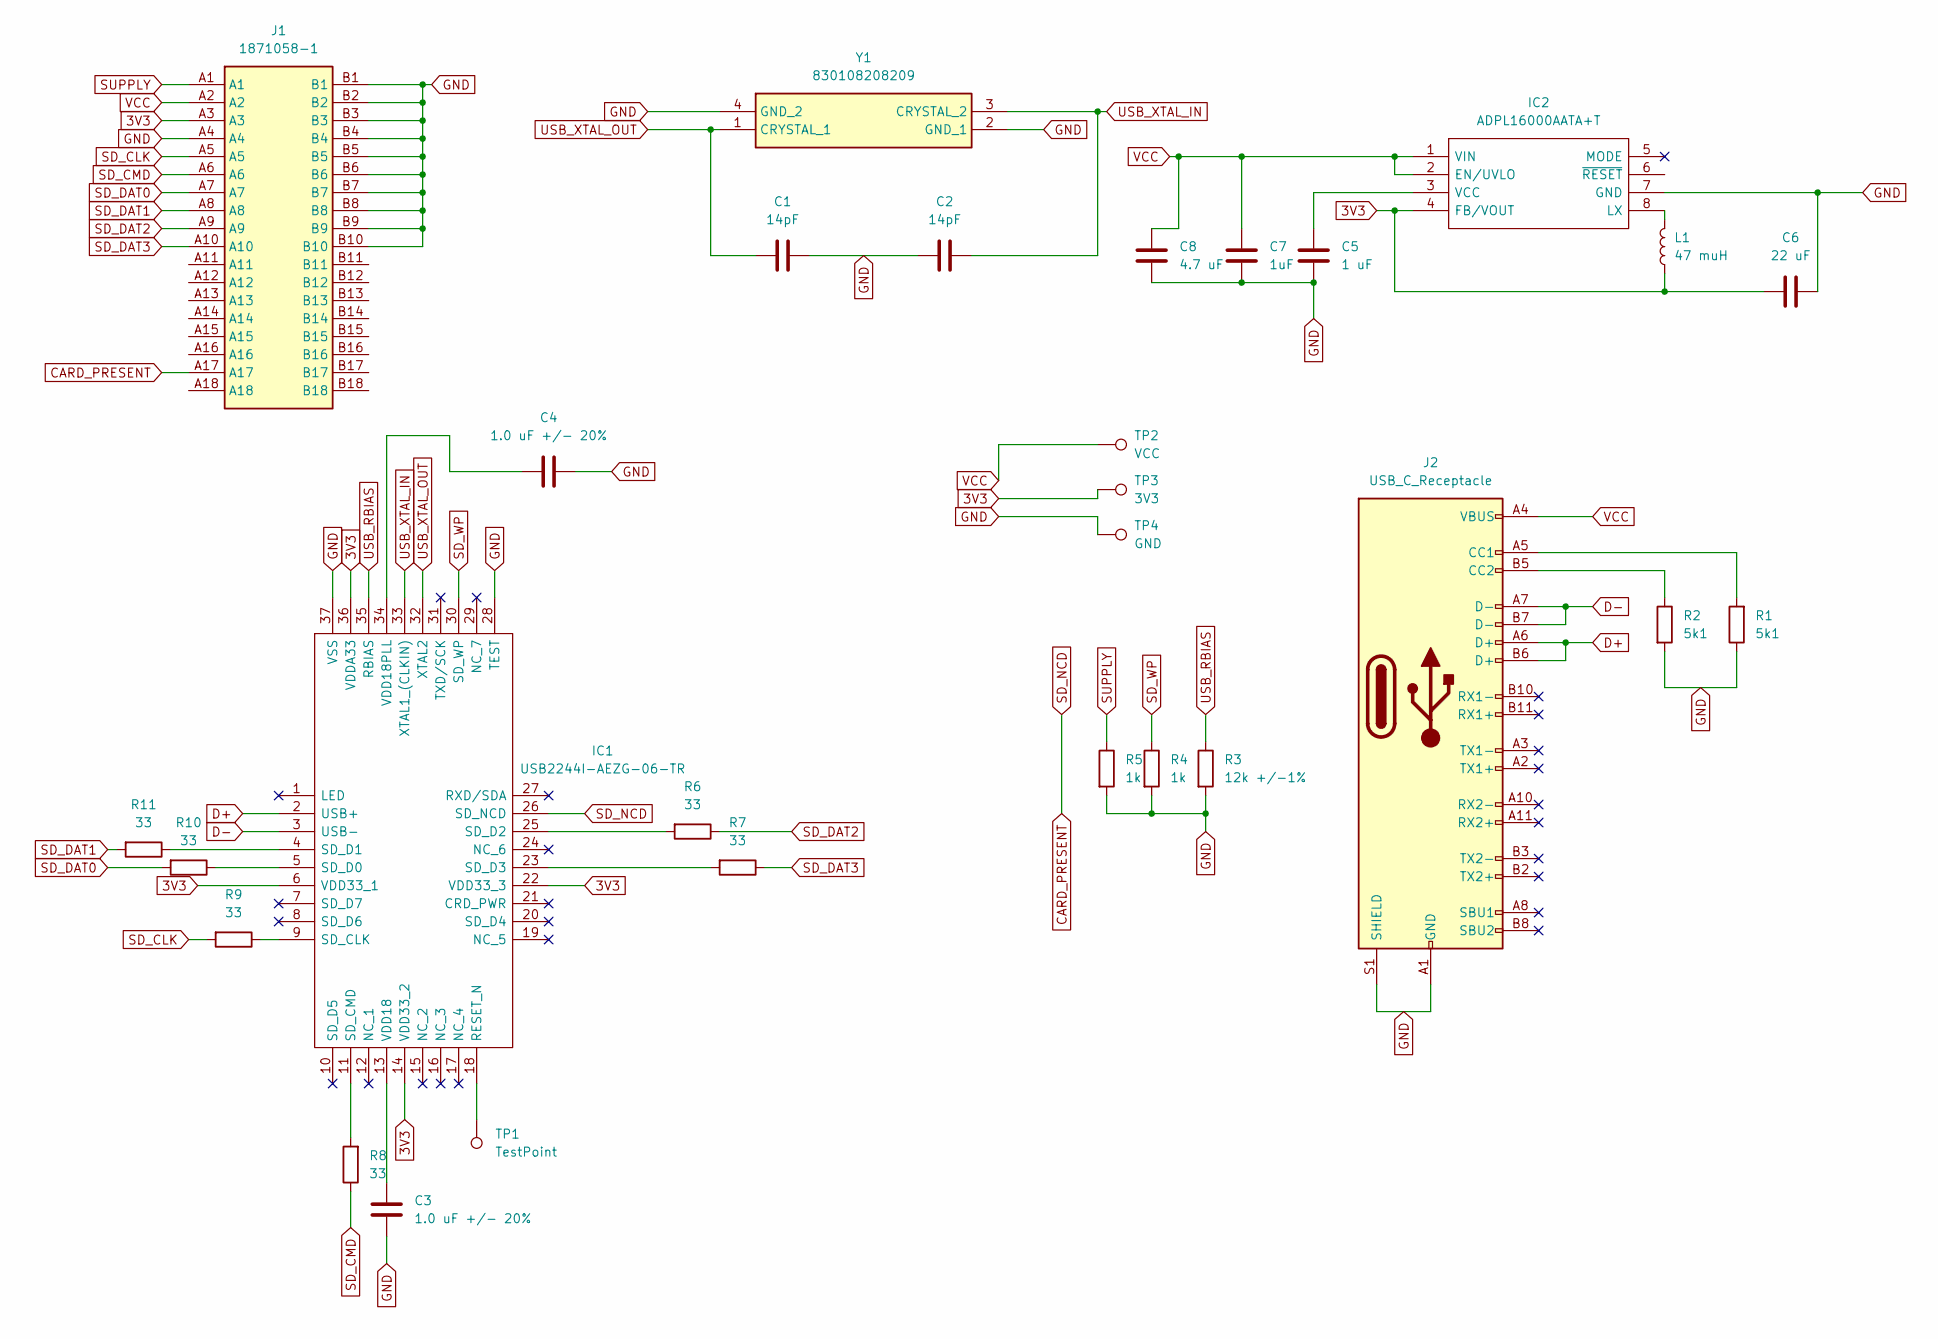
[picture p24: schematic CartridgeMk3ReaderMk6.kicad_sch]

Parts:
C1, C2: 14pF; C_0201_0603Metric
C3, C4: 1.0 uF +/- 20%; C_0201_0603Metric
C5: 1 uF; C_0201_0603Metric
C6: 22 uF; C_1206_3216Metric
C7: 1uF; C_1206_3216Metric
C8: 4.7 uF; C_1206_3216Metric
IC1: USB2244I-AEZG-06-TR; QFN50P600X600X90-37N-D; Manufacturer_Part_Number USB2244I-AEZG-06-TR; Mouser Part Number 579-USB2244IAEZG06TR
IC2: ADPL16000AATA+T; ADPL16000AATAT; Manufacturer_Part_Number ADPL16000AATA+T; Mouser Part Number 700-ADPL16000AATA+T
J1: 1871058-1; 18710581; Manufacturer_Part_Number 1871058-1; Mouser Part Number 571-1871058-1
J2: USB_C_Receptacle; USB_C_Receptacle_Molex_105450-0101
L1: 47 muH; 74404054470
R1, R2: 5k1; R_0201_0603Metric
R3: 12k +/-1%; R_0201_0603Metric
R4, R5: 1k; R_0201_0603Metric
R6, R7, R8, R9, R10, R11: 33; R_0201_0603Metric
TP1: TestPoint; TestPoint_Pad_D3.0mm
TP2: VCC; TestPoint_Pad_D3.0mm
TP3: 3V3; TestPoint_Pad_D3.0mm
TP4: GND; TestPoint_Pad_D3.0mm
Y1: 830108208209; Manufacturer_Part_Number 830108208209; Mouser Part Number 710-830108208209

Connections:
3V3: C6.2, IC1.6 (VDD33_1), IC1.14 (VDD33_2), IC1.22 (VDD33_3), IC1.36 (VDDA33), IC2.4 (FB/VOUT), J1.A3, L1.1, TP3.1
CARD_PRESENT: IC1.26 (SD_NCD), J1.A17
D+: IC1.2 (USB+), J2.A6 (D+), J2.B6 (D+)
D-: IC1.3 (USB-), J2.A7 (D-), J2.B7 (D-)
GND: C1.1, C2.2, C3.2, C4.2, C5.2, C6.1, C7.2, C8.1, IC1.28 (TEST), IC1.37 (VSS), IC2.7 (GND), J1.A4, J1.B1, J1.B2, J1.B3, J1.B4, J1.B5, J1.B6, J1.B7, J1.B8, J1.B9, J1.B10, J2.A1 (GND), J2.A12 (GND), J2.B1 (GND), J2.B12 (GND), J2.S1 (SHIELD), R1.1, R2.2, R3.2, R4.2, R5.2, TP4.1, Y1.2 (GND_1), Y1.4 (GND_2)
unnamed: IC1.18 (RESET_N), TP1.1
unnamed: IC1.9 (SD_CLK), R9.1
unnamed: IC1.11 (SD_CMD), R8.2
unnamed: IC1.5 (SD_D0), R10.1
unnamed: IC1.4 (SD_D1), R11.1
unnamed: IC1.25 (SD_D2), R6.2
unnamed: IC1.23 (SD_D3), R7.2
unnamed: C3.1, IC1.13 (VDD18)
unnamed: C4.1, IC1.34 (VDD18PLL)
unnamed: IC2.8 (LX), L1.2
unnamed: C5.1, IC2.3 (VCC)
unnamed: J2.A5 (CC1), R1.2
unnamed: J2.B5 (CC2), R2.1
SD_CLK: J1.A5, R9.2
SD_CMD: J1.A6, R8.1
SD_DAT0: J1.A7, R10.2
SD_DAT1: J1.A8, R11.2
SD_DAT2: J1.A9, R6.1
SD_DAT3: J1.A10, R7.1
SD_WP: IC1.30 (SD_WP), R4.1
SUPPLY: J1.A1, R5.1
USB_RBIAS: IC1.35 (RBIAS), R3.1
USB_XTAL_IN: C2.1, IC1.33 (XTAL1_(CLKIN)), Y1.3 (CRYSTAL_2)
USB_XTAL_OUT: C1.2, IC1.32 (XTAL2), Y1.1 (CRYSTAL_1)
VCC: C7.1, C8.2, IC2.1 (VIN), IC2.2 (EN/UVLO), J1.A2, J2.A4 (VBUS), J2.A9 (VBUS), J2.B4 (VBUS), J2.B9 (VBUS), TP2.1

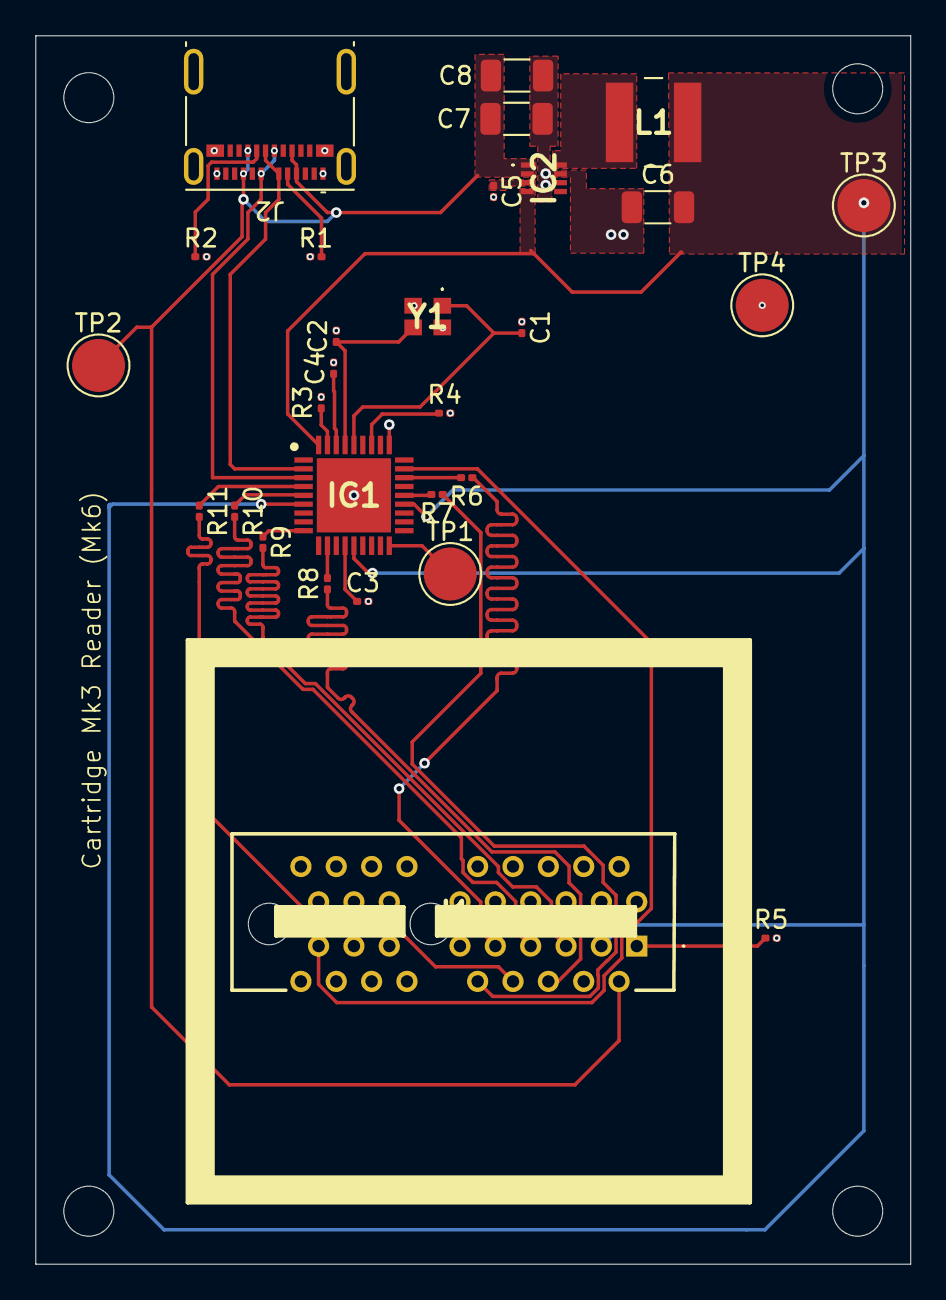
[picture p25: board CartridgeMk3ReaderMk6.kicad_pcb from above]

Board: 2 copper layers, 49.5 x 69.5 mm, 29 parts (0 on the bottom side), 30 nets.

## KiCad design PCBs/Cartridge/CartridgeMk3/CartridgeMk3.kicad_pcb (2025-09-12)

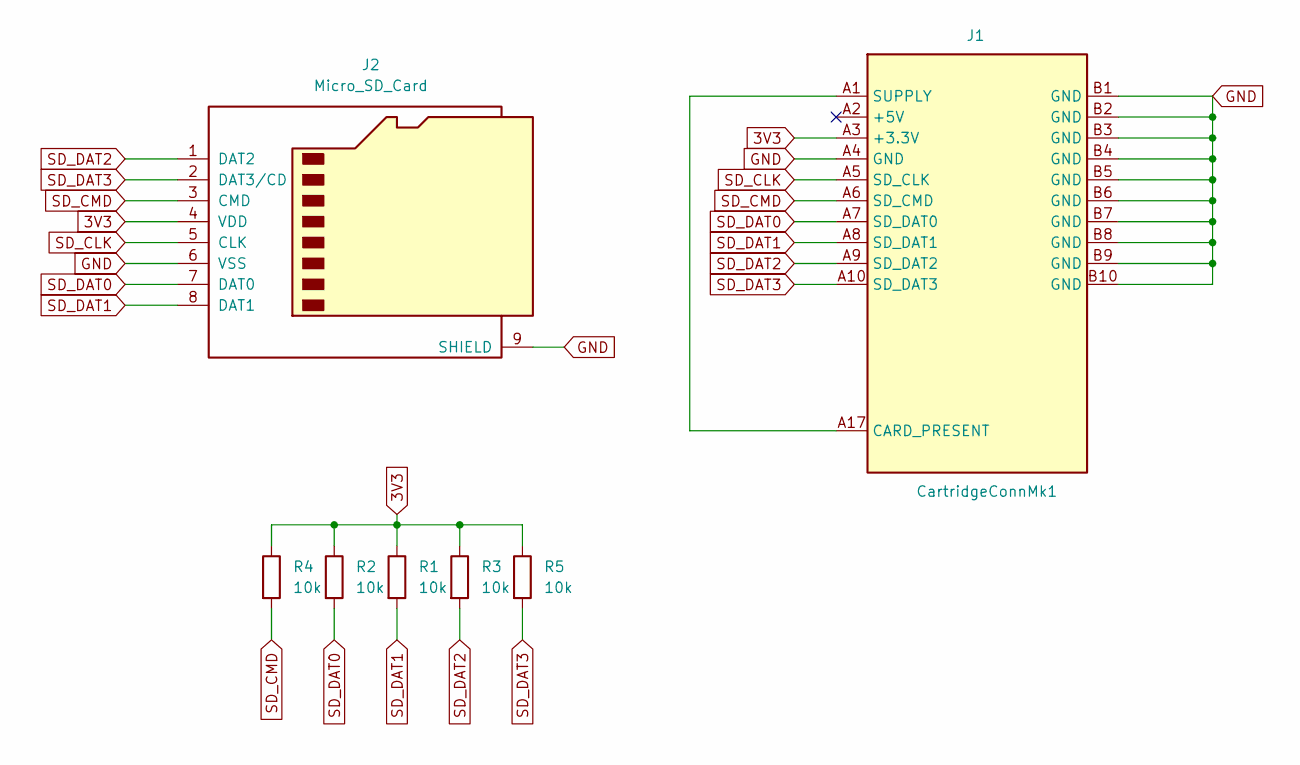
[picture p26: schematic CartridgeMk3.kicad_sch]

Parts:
J1: CartridgeConnMk1; BUS_PCIexpress_x1
J2: Micro_SD_Card; SDCARD_MOLEX_503398-1892
R1, R2, R3, R4, R5: 10k; R_0201_0603Metric

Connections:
3V3: J1.A3 (+3.3V), J2.4 (VDD), R1.1, R2.1, R3.1, R4.1, R5.1
GND: J1.A4 (GND), J1.B1 (GND), J1.B2 (GND), J1.B3 (GND), J1.B4 (GND), J1.B5 (GND), J1.B6 (GND), J1.B7 (GND), J1.B8 (GND), J1.B9 (GND), J1.B10 (GND), J2.6 (VSS), J2.9 (SHIELD)
unnamed: J1.A1 (SUPPLY), J1.A17 (CARD_PRESENT)
SD_CLK: J1.A5 (SD_CLK), J2.5 (CLK)
SD_CMD: J1.A6 (SD_CMD), J2.3 (CMD), R4.2
SD_DAT0: J1.A7 (SD_DAT0), J2.7 (DAT0), R2.2
SD_DAT1: J1.A8 (SD_DAT1), J2.8 (DAT1), R1.2
SD_DAT2: J1.A9 (SD_DAT2), J2.1 (DAT2), R3.2
SD_DAT3: J1.A10 (SD_DAT3), J2.2 (DAT3/CD), R5.2

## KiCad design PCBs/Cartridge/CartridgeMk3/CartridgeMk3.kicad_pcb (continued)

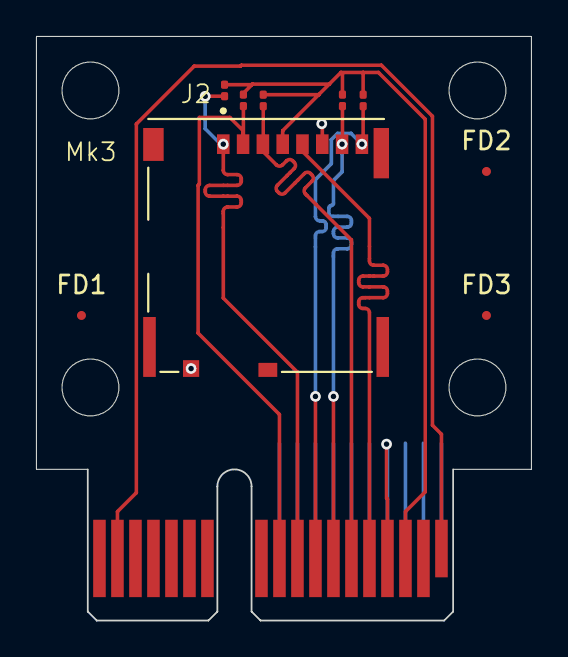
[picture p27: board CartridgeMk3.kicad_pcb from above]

Board: 2 copper layers, 27.5 x 32.5 mm, 10 parts (1 on the bottom side), 9 nets.

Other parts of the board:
FD1, FD2, FD3: Fiducial_0.5mm_Mask1.5mm

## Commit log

2025-09-12 added the dependencies of our pcb designs
    [105450-0101.stp, 1871058-1.SchLib, 1871058-1.stp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]
2025-09-12 added cartridge pcb design
    [CartridgeMk1_simple.step, CartridgeMk3-BoM.csv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]
2025-09-12 added cartridge reader pcb design
    [CartridgeMk3ReaderMk6-B_Cu.gbr, CartridgeMk3ReaderMk6-B_Mask.gbr, CartridgeMk3ReaderMk6-B_Paste.gbr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]
2025-09-12 added keyswitch carrier pcb design
    [KeyswitchCarrierMk3-B_Cu.gbr, KeyswitchCarrierMk3-B_Mask.gbr, KeyswitchCarrierMk3-B_Paste.gbr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]
2025-09-12 added the Mk3 mainboard pcb design
    [Cartridge.kicad_sch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]
2025-09-12 added CAD files and STL exports
    [CartridgeMk2-BackSide.stl, CartridgeMk2-FrontSide.stl, CartridgeMk2-Housing.stl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]
2025-09-18 updated cartridge case files
    Fine-tuned the top part of the cartridge to increase clamping forces of
    things someone might add to the cartridge.
    [CartridgeMk2-BackSide.stl, CartridgeMk2-TopPanel.stl, CartridgeMk2.FCStd]
2025-09-19 removed redundand (old) button versions.
    [LegoCase_Konnexus_Mk1-Quit Button fat.stl, LegoCase_Konnexus_Mk1-Quit Button print.stl, LegoCase_Konnexus_Mk1-Quit Button.stl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]
2025-09-19 tuned the quit button for better snap-fit.
    [LegoCase_Konnexus_Mk1-Quit Button fat Border.stl, LegoCase_Konnexus_Mk1-Quit Button fat revised.stl]
2025-09-20 updated parts of the keys
    [LegoCase_Konnexus_Mk1-Reset Button fat Border.stl, LegoCase_Konnexus_Mk1-Shutdown Button Border.stl]
